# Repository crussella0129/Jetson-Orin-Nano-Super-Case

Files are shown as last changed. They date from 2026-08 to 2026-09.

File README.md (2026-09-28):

# Jetson-Orin-Nano-Super-Case (v3.1a)
An Open Source Desktop Case Design for Nvidia's Jetson Orin Super Developer Kit. 3d printable or CNC machinable in STEP format. **Have Questions, Need Help, or Want One Printed? Email charles@threadandsignal.com**

*For a 'DISCLAIMER OF WARRANTY, ASSUMPTION OF RISK, RELEASE, AND LIMITATION OF LIABILITY' see 'DISCLAIMER.md'*

V3.1a Standard Version - No GPIO/Pin Cutout ("sleek" desktop design)





------------------------------------------------------------------------------------------------------------------------------------------------------

*Some Key Features*

- Bellmouth fan duct and spacious exhaust ports for optimized air cooling. 
- Large cavity for NVMe devices in bottom half, can accomodate permanent heatsinks such as those on "Crucial T705" or SDR/Network cards that are NVMe compatibple
- Plenum system that cycles air from the top of the board to the bottom and out of the case:


------------------------------------------------------------------------------------------------------------------------------------------------------

*Assembly Instructions*

- 3d print:
  - Select the STEP files that meet your needs, import into your slicer as you would an STL file, then print.
    - Slicer Tip: In slicers like Bambu Lab Studio and Prusa Slicer, the import settings will ask you to adjust two sliders. Drag both of them to be as low as possible, such that the total "number of faces" is ~ 1 million faces (more typically can overload the slicer program on most hardware). More detail is higher resolution.
    - Printing Tip: The Figure can be printed oriented as in Fig 1, or can be printed at an angle (Fig 2). For angled printing, select the face indicated in Fig 1 and print at an angle with tree supports, inner and outer brim, and a skirt (see Fig 2). I recommend 3-4 outer layer walls and approx. 15% gyroid infill. The pictured units are printed in regular Bambu Labs PLA on a Bambu Labs X1C and have had no issues with heavy use (much easier printing and more aesthetically pleasing than most other materials too), but for applications outside the envelope of a desktop environment, high temp, high dimensional stability, low conductivity filaments like PA-GF, PC-GF, or PPS-GF, are *recommended* for applications outside of desktop use. With fiber reinforced filaments, it is also recommended during post-processing to use a nylon brush to debride and remove any loose fibers from the surface to prevent them from dislodging and becoming dust that accumulates on your Jetson board. 
    - Fig 1
      

    - Fig 2
      

  - After printing, insert ruthex M3 threaded inserts (this model was made for these: https://www.amazon.com/dp/B08BCRZZS3?ref_=ppx_hzod_title_dt_b_fed_asin_title_0_3&th=1) in the top half's screw holes. Any standard M3 machine screws will work for this design.
    - Tip: The M3 Screws that work best with the file as is are ~15mm, but you can adjust the height of the "inner circle" with an extrude command (in Fusion, Solidworks, etc...) to match what you have on hand.
    - Fig 3
      
 
  - Place a jumper across pins 5 and 6, as in Fig 4, then take the buttons and cut the wires such that the total length is ~110-120mm and place the dupont jumpers on the ends of the cables, as in Fig 5. Attach these to the desired corresponding pins on the button header.
  - Fig 4
    
  - Fig 5
    

  - Place the Jetson Orin Nano Board *CAREFULLY* into the top half of the case. (Fig 4)
  - Fig 6
    

  - Place the top half onto a sturdy table, or work surface, face down. Then, align the bottom half such that the plenum/recess is directly beneath the aux NvME port.
  - Insert the M3 machine screws, then tighten, to attach the two halves.
  - Use rubber feet, if desired, to minizmize sliding or wobble.
     
- CNC Machining:
  - Offset the screwholes on the top half down to a total diameter of ~2.6mm, \
  - hand tap.
  - Assemble as instructed above in "3d print".
 
Latest Updates (V3.1a): 
- Complete redesign based on lessons learned throughout the 2.X series; more internal cavity volume, elimination of ~93% of support material needed, ~4% reduction in global max volume, and aesthetic refinements.
- Added the third 12.2mm hole for power, reset, and sys recovery mode buttons (utilizing the entire button header), available here: https://www.amazon.com/gp/product/B09BKWMNJ9/ref=ox_sc_act_title_1?smid=ALOZL3MQGX35O&th=1

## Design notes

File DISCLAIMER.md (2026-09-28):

# DISCLAIMER OF WARRANTY, ASSUMPTION OF RISK, RELEASE, AND LIMITATION OF LIABILITY

This design is intended only for use with the official NVIDIA Jetson Orin Nano Super Developer Kit. It has not been tested with and is not recommended for use with counterfeit, cloned, third-party, modified, or custom carrier boards or other hardware configurations.

This design is not endorsed, certified, or approved by NVIDIA. No representation is made that it provides adequate cooling, electrical isolation, mechanical protection, access protection, or other safety measures for any particular application.

NVIDIA states that its Jetson software is not designed or tested for use in systems or applications whose use or failure could result in injury, death, or catastrophic damage (“Mission Critical Applications”). This design, including any modification or derivative of it, is likewise not intended, tested, or certified for Mission Critical Applications. Use of this design does not make the NVIDIA hardware, software, or any system incorporating them suitable, tested, or certified for Mission Critical Applications. See the [NVIDIA JetPack End User License Agreement](https://docs.nvidia.com/jetson/jetpack/eula/) for NVIDIA's applicable terms concerning Mission Critical Applications.

This design and all associated files, documentation, and information are provided **“AS IS”** and without warranties of any kind, express or implied, to the maximum extent permitted by applicable law.

To the maximum extent permitted by applicable law, by manufacturing, assembling, modifying, installing, or using this design, you voluntarily assume the risks associated with such activities and waive and release the designer(s), contributor(s), and distributor(s) from claims arising from such manufacture, assembly, modification, installation, or use.

By manufacturing, assembling, modifying, installing, or using this design, you acknowledge and assume all risks associated with doing so. Such risks may include, without limitation, damage to equipment or other property, loss of materials, work product, or billable time, electrical or thermal damage, fire, personal injury, or death.

This design is intended solely for lawful purposes and lawful use. Users are solely responsible for ensuring that their manufacture, modification, installation, and use of the design, including any physical components manufactured from or used in conjunction with the design, complies with all applicable laws and regulations.

You are solely responsible for determining whether the design is appropriate and safe for your particular equipment, materials, manufacturing process, environment, and intended use.

To the maximum extent permitted by applicable law, the designer(s), contributor(s), and distributor(s) shall not be liable for any direct, indirect, incidental, special, consequential, or other damages arising from the manufacture, assembly, modification, installation, or use of the design.

This disclaimer is intended to apply to all versions and revisions of the design authored and distributed through this repository, including versions made available before the addition or publication of this disclaimer, to the maximum extent permitted by applicable law. Nothing in this statement should be construed as creating a warranty or assumption of liability with respect to any prior version of the design.

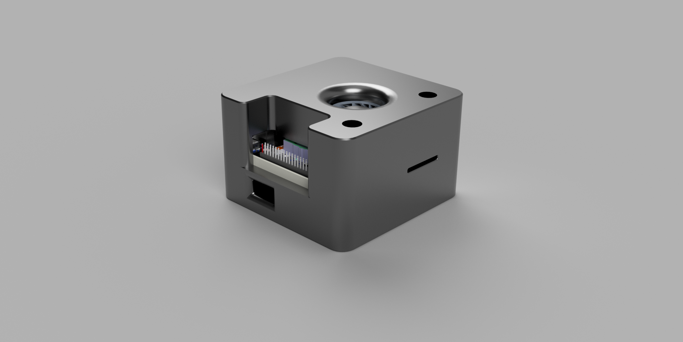
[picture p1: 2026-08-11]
v2.2/Images/Jetson Case v2.2 Open Design.png

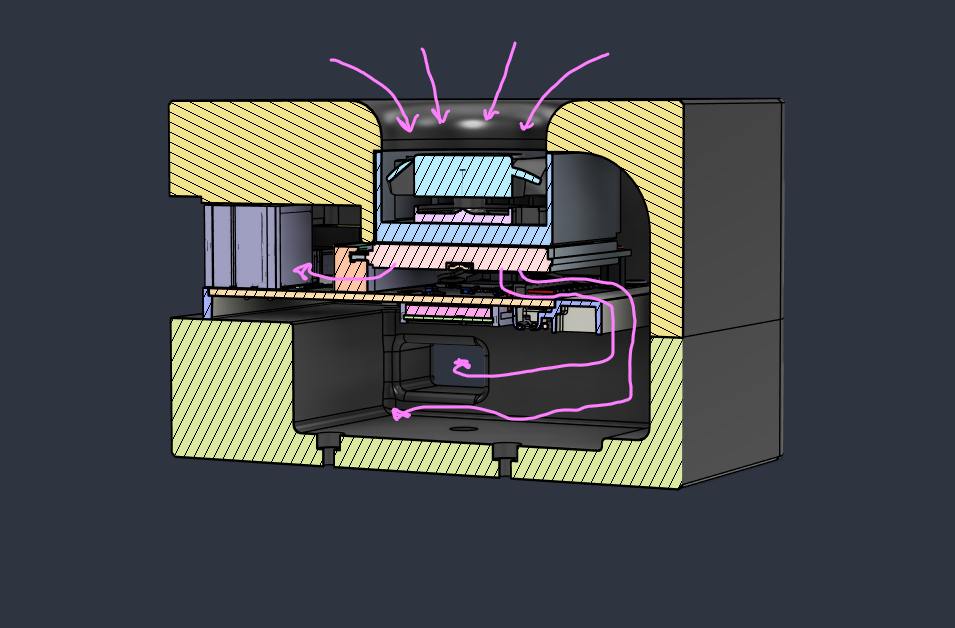
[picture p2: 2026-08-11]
v2.2/Images/Jetson Case v2.2_cutaway.png

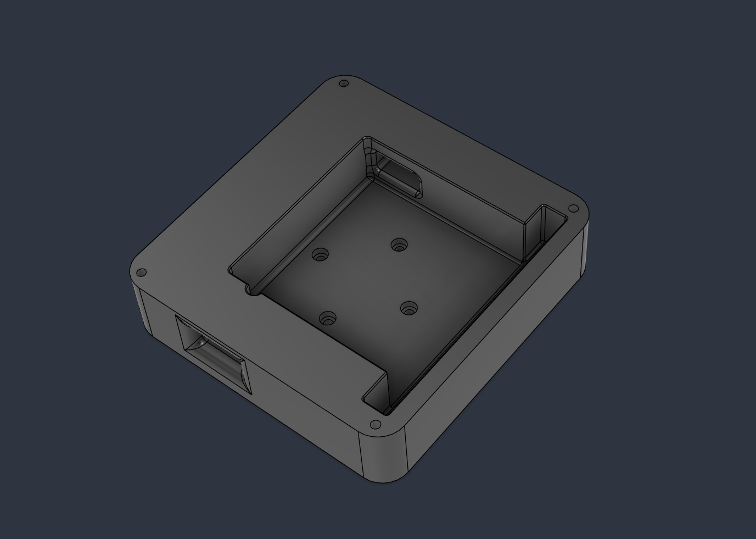
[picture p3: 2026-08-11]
v2.2/Images/Jetson Case v2.2 - mounting holes.png

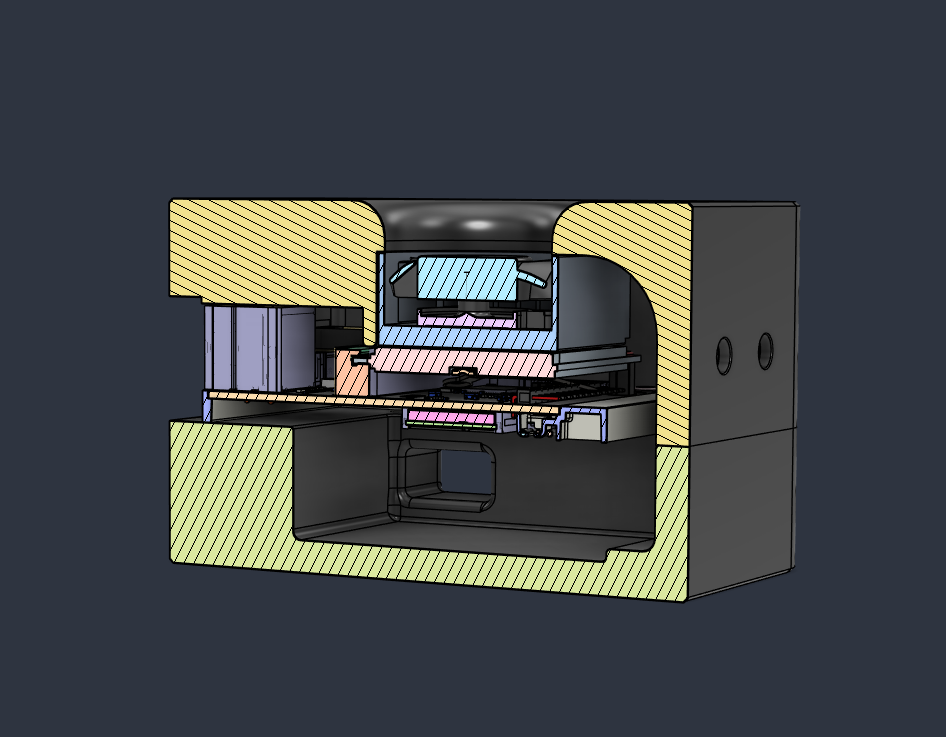
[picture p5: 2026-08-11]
v2.3 - LiteXM2SDR/Jetson Case v2.3 - LiteXM2SDR Cutaway.png

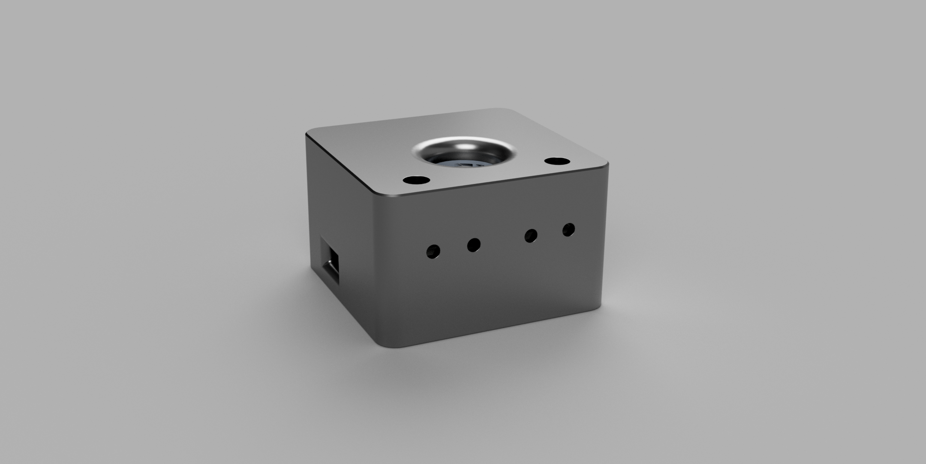
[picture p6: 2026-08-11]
v2.3 - LiteXM2SDR/Jetson Case v2.3 - LiteXM2SDR.png

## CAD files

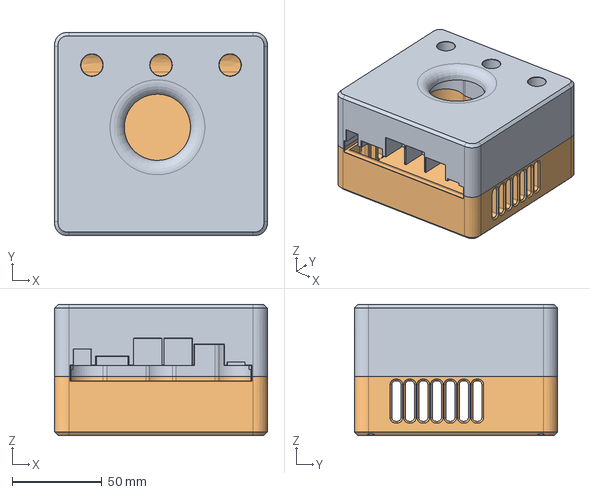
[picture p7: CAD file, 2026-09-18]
Jetson Case v3.1a.step
119.0 x 113.5 x 73.3 mm

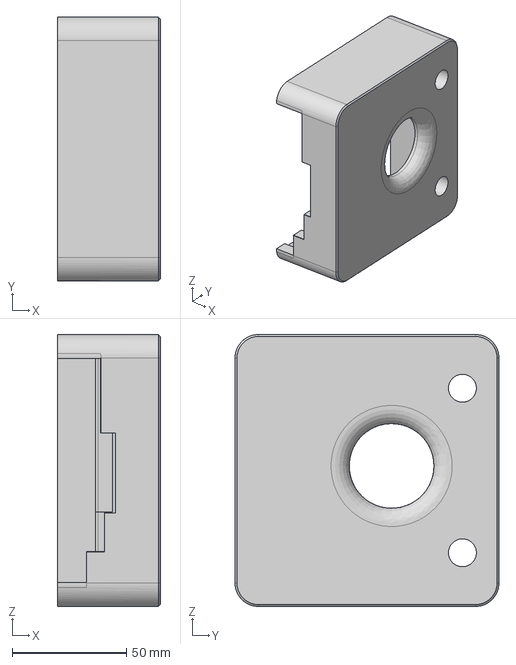
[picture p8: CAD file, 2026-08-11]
v2.2/Jetson Case v2.2 - Upper Half - Enclosed w Buttons.step
45.0 x 115.5 x 119.0 mm

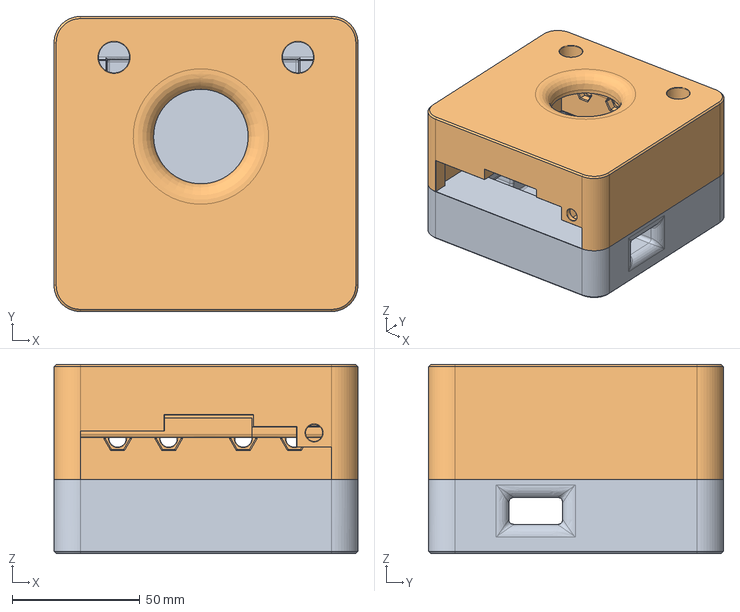
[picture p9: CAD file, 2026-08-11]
v2.3 - LiteXM2SDR/Jetson Case v2.3 - LiteXM2SDR.step
119.0 x 115.5 x 74.0 mm

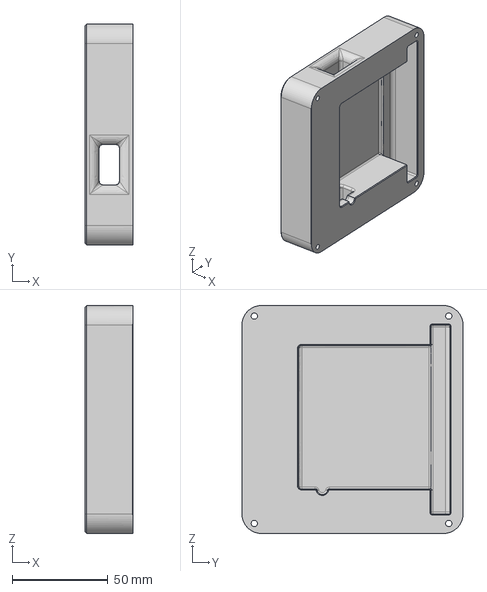
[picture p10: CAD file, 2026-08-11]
v2.2/Jetson Case v2.2 - Lower Half - No Mount.step
25.0 x 115.5 x 119.0 mm

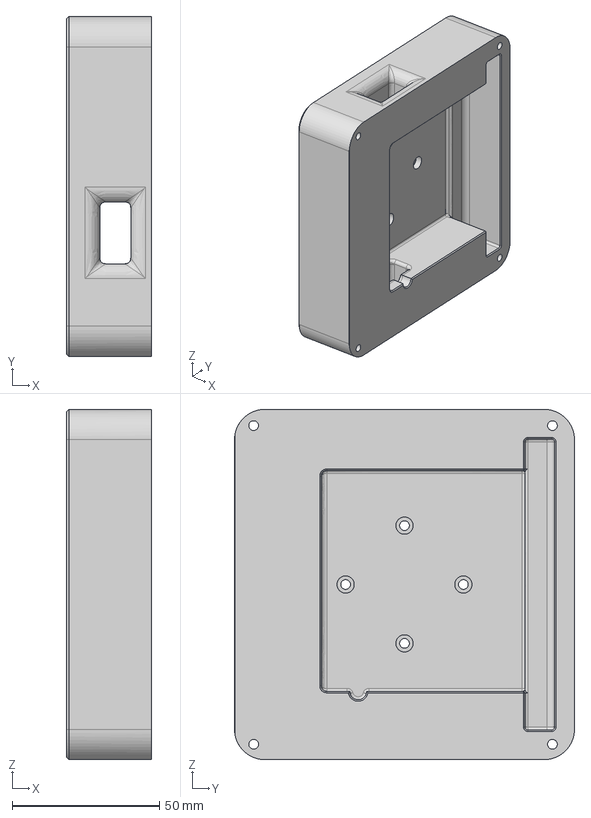
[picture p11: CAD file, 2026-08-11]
v2.2/Jetson Case v2.2 - Lower Half - Mountable.step
29.0 x 115.5 x 119.0 mm

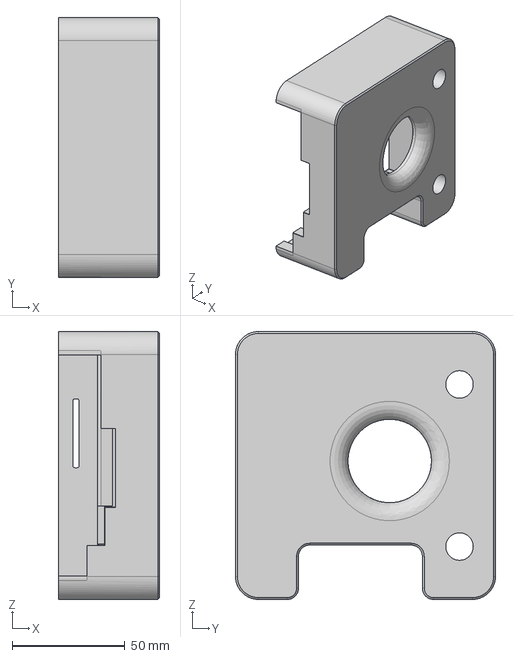
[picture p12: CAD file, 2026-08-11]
v2.2/Jetson Case v2.2 - Upper Half - Open Design.step
45.0 x 115.5 x 119.0 mm

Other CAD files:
v2.2/Jetson Case v2.2 - Upper Half - Enclosed no Buttons.step

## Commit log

2026-01-28 Add files via upload
    Added the standard version (no GPIO Cutout) as well as one with a cutout for the GPIO if needed.
    [Case (With GPIO Cutout).step, Case.step]
2026-01-28 Added corrected top half
    [Case_V1.3_UHalf_GPIOcutout.step, Case_V1.3_UHalf_NoGPIO.step]
2026-01-28 Update and rename Case_V1.2_LHalf_Vented.step to Case_V1.3_LHalf_Vented.step
    [Case_V1.3_LHalf_Vented.step]
2026-01-28 Update and rename Case_V1.2_LHalf_novent.step to Case_V1.3_LHalf_novent.step
    [Case_V1.3_LHalf_novent.step]
2026-01-28 Add files via upload
    Fixed issues with compatibility with some m3 machine screws
    [Case_V1.3_LHalf_Vented.step.step, Case_V1.3_LHalf_novent.step.step]
2026-01-28 Added v1.4 models
    - Consolidated top and bottom halves into one STEP assembly (can be disasembled into objects in your preferred slicer (Bambu, Prusa, etc...)
    - Re-designed, adding an 'internal plenum' to get air from the fan to the bottom of the board to cool nvme drives
    - Increased the size of the vents on the bottom half for better NVME airflow
    [Case_V1.4_noGPIO.step, Case_v1.4_wGIPO.step]
2026-01-29 Screwhead Diameter Issue Addressed (Again)
    [Case_V1.6_noGPIO.step, Case_v1.6_wGIPO.step]
2026-01-29 Update README.md
    Added more detailed instructions for 3d printing.
2026-01-29 Add files via upload
    Added V2.0, which eliminates side holes and focuses on using the plenum and lower exhaust ports to cycle air around the entire board (and SSDs). Also looks sleeker. Kept V1.6 as it was essentially al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
    [Case_V1.6_noGPIO.step, Case_V2.0_nopins.step, Case_V2.0_wpins.step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]
2026-02-16 Revise printing tips in README.md
    Updated printing tips for clarity and filament recommendations.
2026-02-23 Revise assembly instructions and add version updates
    Updated assembly instructions and added latest updates for version 2.1.
2026-08-11 v2.2 and v2.3 upload
    v2.2 features some major updates such as adjustments for printability (with little to no exterior changes), fixing an issue with the power button mounts (and offering both a buttoned and buttonless version), the addition of a version of the lower half with mounting holes for mounting to stationary, extrusion structures, or for more securely mounting within an immobilization harness of your own design (for vehicles and drones). v2.3 is hosted on the fork branch at https://github.com/dkozel/orin-nano-litex-m2-sdr-case and is a specialized variant for the LiteXM2 SDR. This copy acts as a mirror back to main. Check out the fork for more information on this super interesting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
    [Jetson Case v2.2 - Lower Half - Mountable.step, Jetson Case v2.2 - Lower Half - No Mount.step, Jetson Case v2.2 - Upper Half - Enclosed no Buttons.step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]
2026-08-11 folder renaming to match convention
    [Jetson Case v2.2 - Lower Half - Mountable.step, Jetson Case v2.2 - Lower Half - No Mount.step, Jetson Case v2.2 - Upper Half - Enclosed no Buttons.step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]
2026-08-11 deletion of obsolete files
    [Case_V1.6_noGPIO.step, Case_V2.0_nopins.step, Case_V2.0_wpins.step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]
2026-09-15 v3.0 revised case w/chamfer edges
2026-09-16 Update README to reflect current version and features
    Removed outdated version descriptions and images for V2.0 and V1.6. Updated feature descriptions for improved clarity.
2026-09-16 Update README for Jetson Orin Nano Super Case v3.0
    Updated version number and description for the case design.
2026-09-18 v3.1a upload
    v3.1a (No GPIO Port/Mounts), Desktop Model
    [Jetson Case v3.1a.step]
2026-09-21 Update README with contact email for inquiries
    Added contact information for inquiries about the case design.
2026-09-21 Revise 3D printing tips and filament recommendations
    Updated printing tips for 3D printing, including filament recommendations and post-processing advice.
2026-09-21 Update assembly instructions in README
    Clarified slicer settings for optimal face count and added recommendations for high-temp filaments and post-processing.
2026-09-28 Add disclaimer for design usage and liability
    Added a comprehensive disclaimer regarding warranty, risks, and limitations of liability for the design intended for the NVIDIA Jetson Orin Nano Super Developer Kit.
